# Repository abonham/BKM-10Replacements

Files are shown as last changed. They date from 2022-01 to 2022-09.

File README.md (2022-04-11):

# BKM-10Replacements
BKM-10Replacements are cheap microcontroller based alternative for the Sony BKM-10R control unit typically used with Sony broadcast monitors like the BVM-D20F1a/e/u.

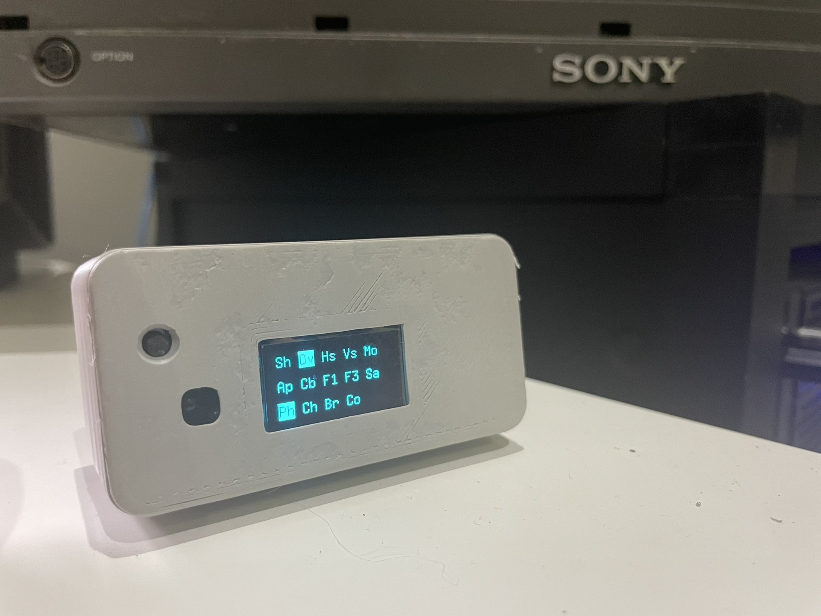
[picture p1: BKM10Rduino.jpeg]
Finished board


The most up-to-date version is BKM10-Rp2040, based on the Raspberry Pico. See the docs in that directory for setup instructions.

## Why?
BVM and PVM CRTs are rather popular with retro gaming enthusiasts, but they are being priced out of reach for the average fan. I managed to rescue a BVM-D20F1A that was destined for e-waste. Of course it was missing the control unit and it was stuck on the SDI input. One spare Arduino Nano, a couple of components, and a lot of swearing later, I had something good enough to use the menus to change inputs and do basic setup. With the help of Martin (@skumlos), this evolved in to a universal IR based replacement.

## What's it do?
Allows the use of almost any IR remote you might have lying around to control any BVM compatible with the BKM-10R. It's configurable through a learning mode, so it's kind of like using a universal remote control, if you remember those from the late 90s. All the buttons on the BKM-10R are replicated, and all status LEDs are displayed on an OLED screen.

There's no problem assembling this on a breadboard, but there are KiCAD schematics, PCB designs and gerber files included if you'd like a more polished finised product.

## Warning
I'm not an electrical engineer. I don't know enough to know when I'm doing something stupid or dangerous. Goes without saying that there is absolutely no warranty; if your precious monitor explodes, I will be very sympathetic and sorry, but that's all. Proceed at your own risk.

If you want to build the PCB version, there are some SMT components, so a least a bit of soldering experience is highly recommended.
## Thanks
I found the control codes on an anonymous [pastebin](https://pastebin.com/aTUWf33J), so must thank this unknown hero.

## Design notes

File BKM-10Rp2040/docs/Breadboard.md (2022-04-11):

# Instructions for building on a breadboard
This is pretty straight forward to build on a breadboard and the only tricky to source part will be the RS485 component.

## BOM
- Raspberry Pico
- [RS485](#rs485) module or IC on breakout
- Hook up wire
- Standard breadboard
- some kind of serial cable

### Optional
#### Display – I2C OLED
- SH1106 or SSD1306

#### IR
- TSOP34xxx IR Receiver
- Remote control w/ 36+ buttons, [NEC IR format](#nec-ir)
- Tact switch (1)

#### Buttons
- Tactile switch/button (5)

## Pinout

|Pin |Dest  |
|---|---|
|GPIO3|IR Out|
|GPIO4 (SDA) | OLED SDA  |
|GPIO5 (SCL) | OLED SCL  |

|Buttons|Pin|
|---|---|
| IR Learn | GPIO2 |
| Power | GPIO15 |
| Menu | GPIO16 |
| Up | GPIO17 |
| Down | GPIO14 |
| Enter | GPIO18 |

### RS485

|RS485|Pin|
|---|---|
|DI|GPIO0 (TX)|
|RO|GPIO1 (RX)|
|DE|GPIO6|
|RE - Full Duplex|GPIO7|
|RE - Half Duplex|GND|

```
GND B   -   -   VCC
1   2   3   4   5
°   °   °   °   ° 
  °   °   °   °
  6   7   8   9    
  -   A   -   -
```
_Looking at front of Male DB9_

### Power
There two ways to power this thing, from USB through the Pico, or directly from the BVM. For initial testing, it is recommended to take power from the Pico, then once it all checks out, switch to take power from the serial cable.

|RS485|Pico|
|---|---|
|VCC|VBUS or VSYS*|
|GND|Any ground|

*If your RS485 solution can operate off 3.3V, then VSYS is the preferred option.

|RS485|DB9|
|---|---|
|VCC|Pin 5|
|GND|Pin 1|

Can also be handy to add a button between RUN and GND for easy reset.

## Firmware
The repo contains two pre-built binaries for the Pico, choose the one that matches you OLED driver, if using a display. If you aren't using the display, then just pick either, it won't matter. 

You can also download pre-built firmware from the latest successful [GitHub action](https://github.com/abonham/BKM-10Replacements/actions)
## Notes
### RS485
There's a few options for RS485: a breakout like the [MAX485](https://core-electronics.com.au/ttl-uart-to-rs485-converter-module.html) or using any bare IC like the [Analog Devices ADM3065E](https://www.analog.com/en/products/adm3065e.html).

If using a breakout board, there don't seem to be any available in full duplex, so it won't be able to receive status updates from the BVM. You can of course just use two; one each for TX and RX.

A bare IC is of course going to require advanced soldering skills and either a SOIC breakout board. With even more advanced skills and it could also be dead bugged.

### NEC IR
Most non-Sony IR remote controls will use the NEC command format, but there are a few other formats out there too. If in doubt, try a couple in learning mode.

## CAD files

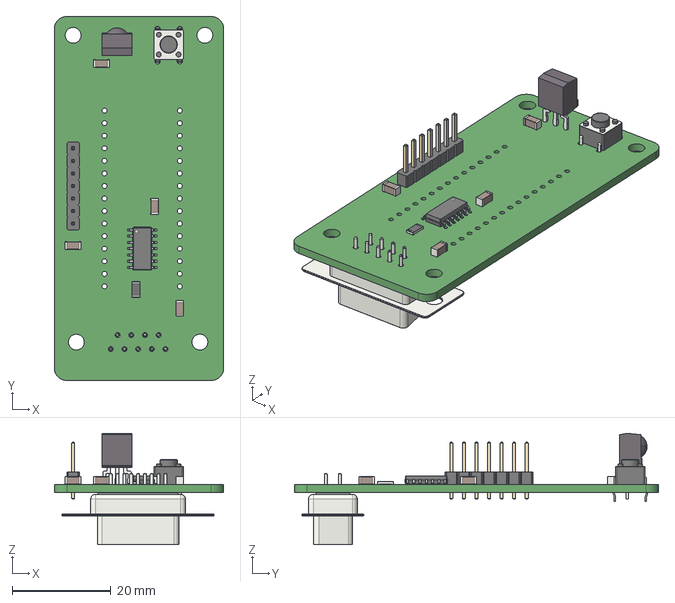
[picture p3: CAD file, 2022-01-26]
BKM-10Rduino/kicad/bkm10iRduino_shield.step
34.3 x 73.7 x 22.5 mm

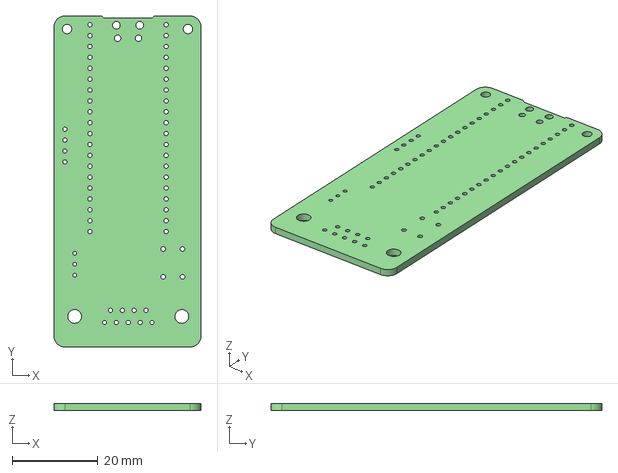
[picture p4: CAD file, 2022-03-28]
BKM-10Rp2040/kicad/BKM-10Rp2040 v2.step
34.3 x 77.2 x 1.60 mm

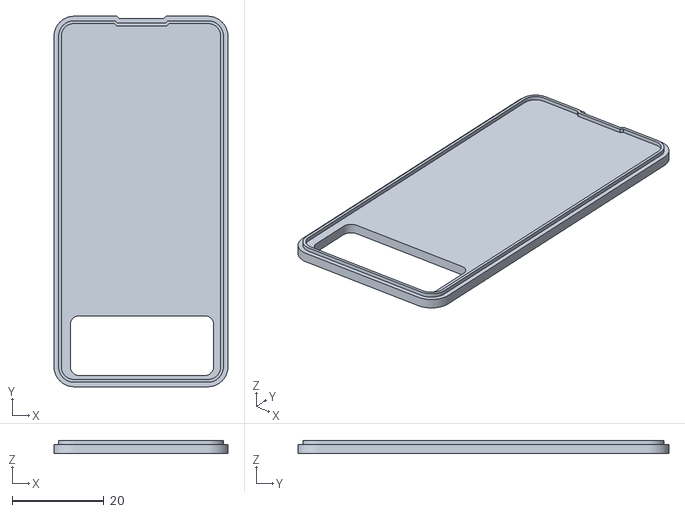
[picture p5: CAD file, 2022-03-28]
BKM-10Rp2040/Lid.stl
38.0 x 80.9 x 2.80

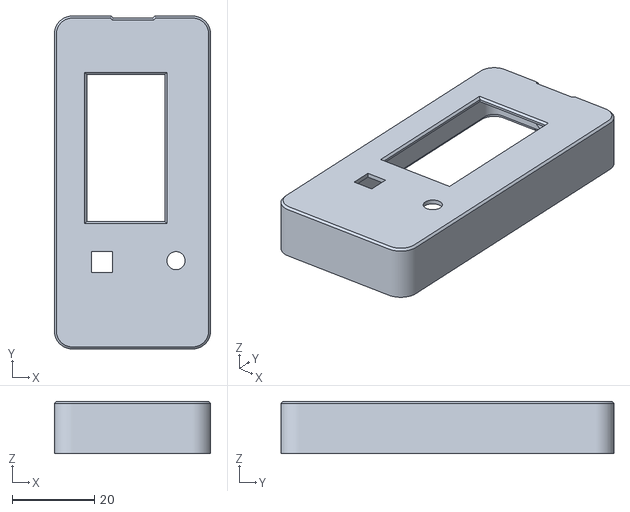
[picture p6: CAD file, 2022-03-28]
BKM-10Rp2040/Case.stl
38.0 x 80.9 x 12.7

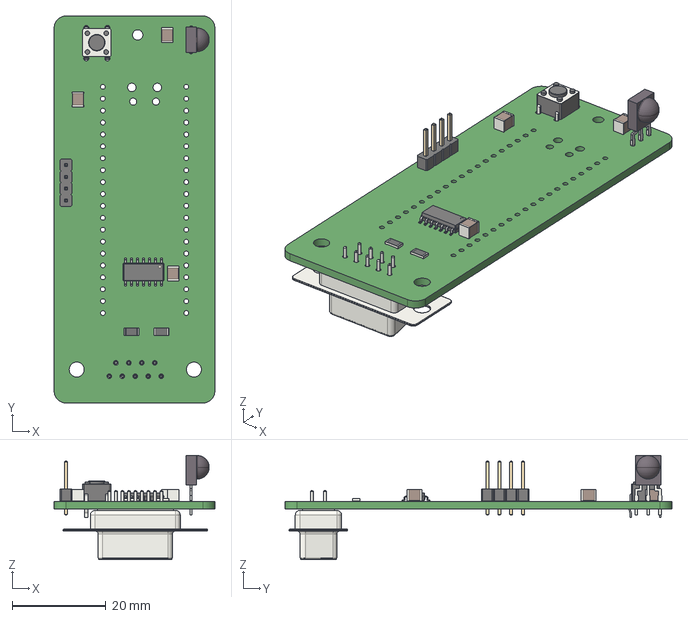
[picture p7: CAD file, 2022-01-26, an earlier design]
BKM-10Rp2040/kicad/BKM-10Rp2040.step
34.3 x 82.5 x 22.2 mm

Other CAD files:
BKM-10Rp2040/bkm2040 v6.f3d

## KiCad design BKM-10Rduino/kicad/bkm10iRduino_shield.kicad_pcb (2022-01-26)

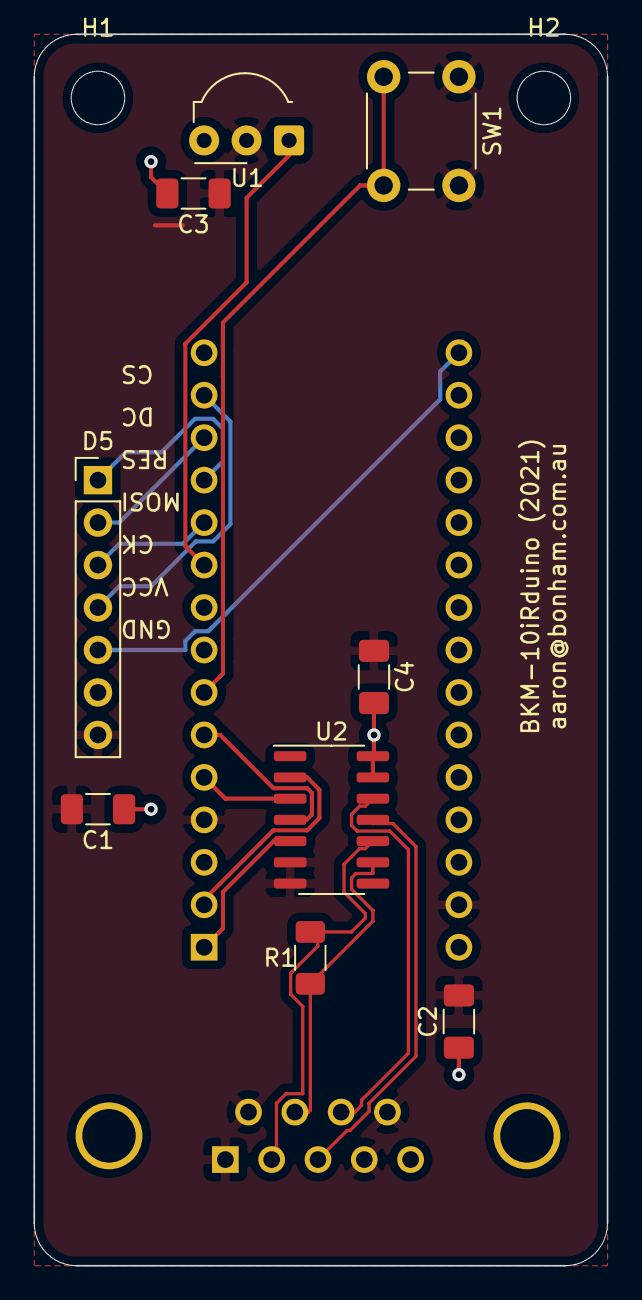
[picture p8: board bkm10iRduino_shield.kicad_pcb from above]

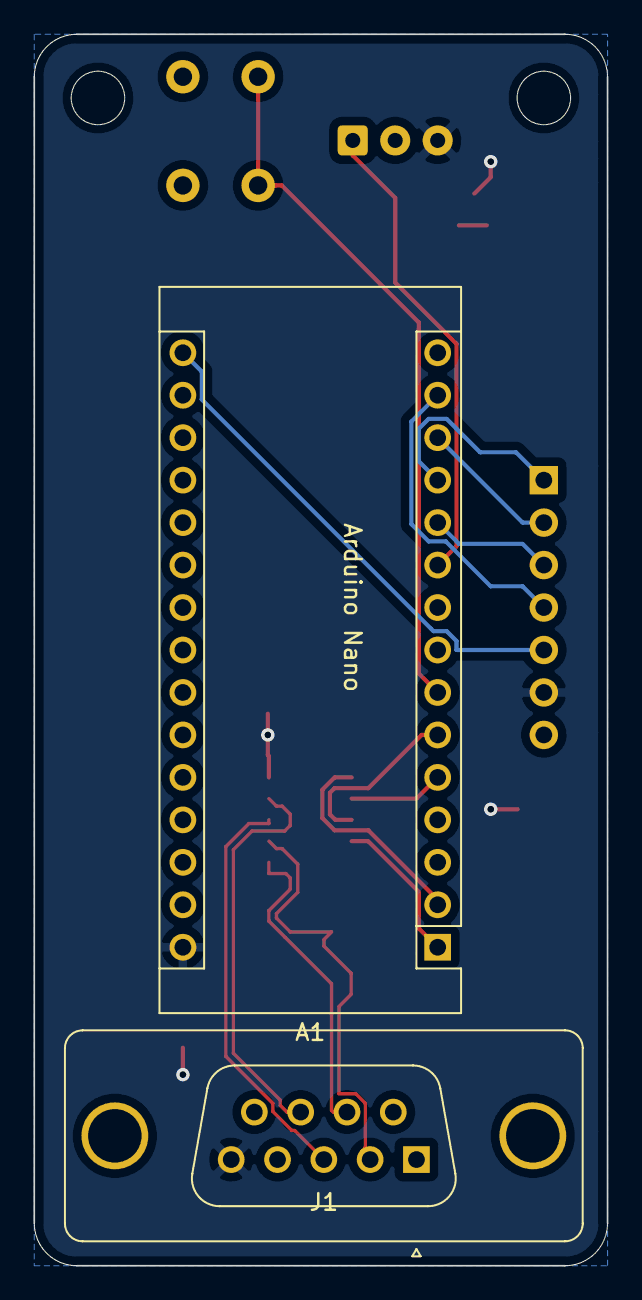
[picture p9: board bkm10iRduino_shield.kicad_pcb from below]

Board: 2 copper layers, 34.3 x 73.7 mm, 13 parts (2 on the bottom side), 17 nets.

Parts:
A1: Arduino_Nano_Every; Arduino_Nano
C1, C2, C3, C4: C_Small; C_1206_3216Metric_Pad1.33x1.80mm_HandSolder
D5: SH1106; PinHeader_1x07_P2.54mm_Vertical
H1, H2: MountingHole; MountingHole_3.2mm_M3
J1: DB9_Male; DSUB-9_Male_Vertical_P2.77x2.84mm_MountingHoles
R1: R; R_1206_3216Metric_Pad1.30x1.75mm_HandSolder
SW1: SW_SPST; SW_PUSH_6mm_H5mm
U1: TSOP343xx; Vishay_MOLD-3Pin
U2: ADM3063EARZ-ND; SOIC-14_3.9x8.7mm_P1.27mm

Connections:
AB+: J1.3, U2.11
AB-: J1.8, U2.12
CS: A1.12, D5.1
DC: A1.13, D5.2
GND: A1.4, A1.29, C1.2, C2.2, C3.1, C4.1, D5.7, J1.1, J1.4, J1.6, J1.9, SW1.1, U1.2, U2.6, U2.7
IR_OUT: A1.10, U1.1
LEARN_BUTTON_IN: A1.7, SW1.2
MOSI: A1.14, D5.4
RES: A1.11, D5.3
RS485_RX: A1.2, U2.2
RS485_RX_ENABLE: A1.5, U2.3
RS485_TX: A1.1, U2.5
RS485_TX_ENABLE: A1.6, U2.4
SCK: A1.16, D5.5
VCC: A1.30, C1.1, C2.1, C3.2, C4.2, D5.6, J1.5, U1.3, U2.13, U2.14
YZ+: J1.7, R1.1, U2.9
YZ-: J1.2, R1.2, U2.10

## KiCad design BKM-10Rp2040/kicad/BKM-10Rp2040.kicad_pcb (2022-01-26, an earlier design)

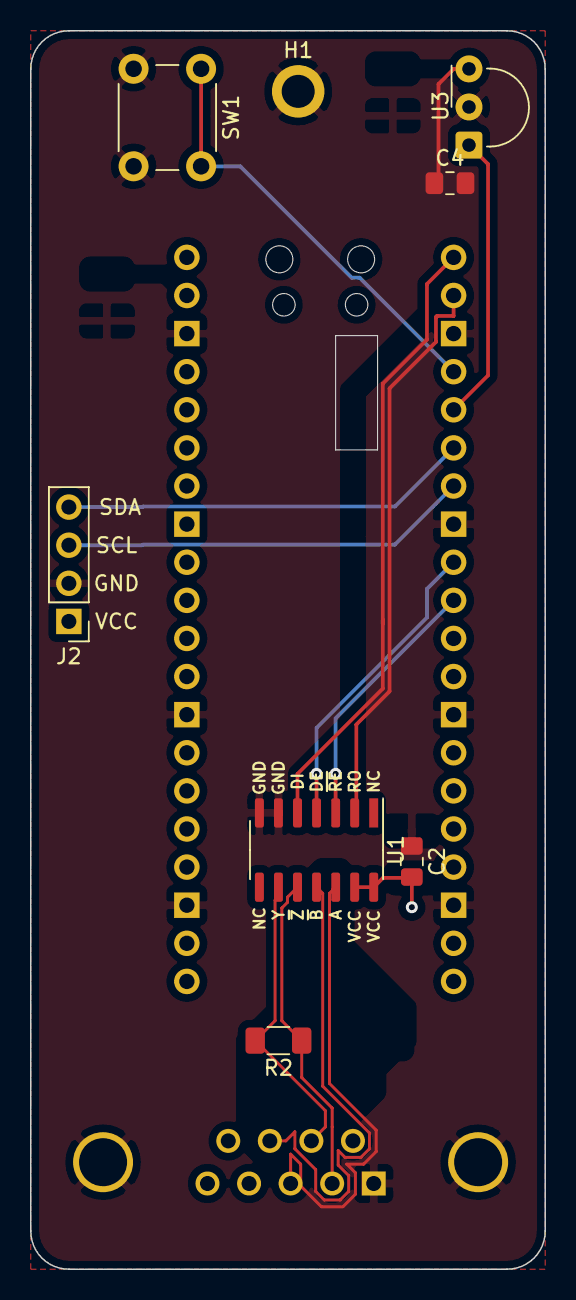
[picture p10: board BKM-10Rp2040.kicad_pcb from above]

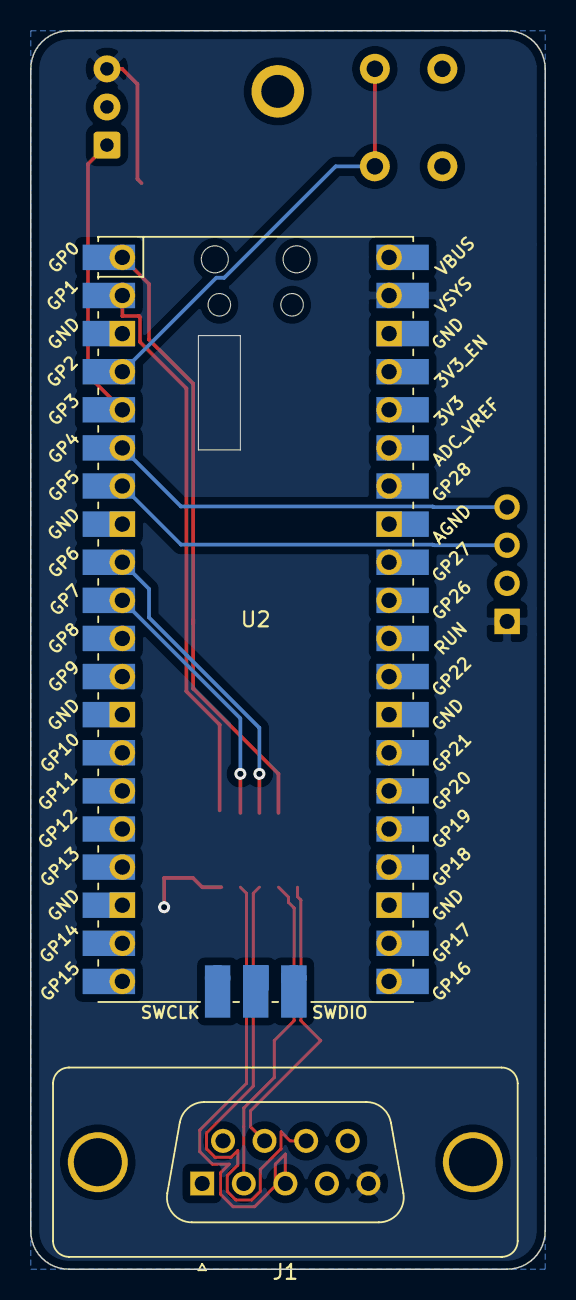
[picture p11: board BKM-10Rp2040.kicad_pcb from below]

Board: 2 copper layers, 34.3 x 82.5 mm, 10 parts (2 on the bottom side), 14 nets.

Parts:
C2, C4: 0.1uF; C_0805_2012Metric_Pad1.18x1.45mm_HandSolder
H1: MountingHole_Pad; MountingHole_2.2mm_M2_ISO7380_Pad
J1: DB9_Female_MountingHoles; DSUB-9_Female_Vertical_P2.77x2.84mm_MountingHoles
J2: Conn_01x04; PinHeader_1x04_P2.54mm_Vertical
R2: 60R; R_1206_3216Metric_Pad1.30x1.75mm_HandSolder
SW1: SW_DPST_x2; SW_PUSH_6mm
U1: ADM3063EARZ-ND; SOIC-14_3.9x8.7mm_P1.27mm
U2: Pico; RPi_Pico_SMD_TH
U3: TSOP335xx; Vishay_MINIMOLD-3Pin

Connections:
+5V: C2.2, C4.1, J1.5, J2.1, U1.13, U1.14, U2.39, U3.3
DE: U1.4, U2.9
GND: C2.1, C4.2, H1.1, J1.0, J1.1, J2.2, SW1.2, U1.6, U1.7, U2.3, U2.8, U2.13, U2.18, U2.23, U2.28, U2.38, U3.2
IR: U2.5, U3.1
LEARN: SW1.1, U2.4
RX: U1.2, U2.2
RXD+: J1.3, U1.12
RXD-: J1.8, U1.11
SCL: J2.3, U2.7
SDA: J2.4, U2.6
TX: U1.5, U2.1
TXD+: J1.7, R2.2, U1.9
TXD-: J1.2, R2.1, U1.10
~RE~: U1.3, U2.10

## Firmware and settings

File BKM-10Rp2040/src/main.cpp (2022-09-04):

// #define SSD1306
#define NO_LED_FEEDBACK_CODE

#include "BKM10Rduino.h"
#include <TinyIRReceiver.h>
#include "IR.h"
#include "store.hpp"
#include "display.h"

extern "C" {
#include "pico.h"
#include "pico/time.h"
#include "pico/bootrom.h"
#include <pico-sdk/rp2_common/hardware_watchdog/include/hardware/watchdog.h>
}
// UART Serial2(0, 1, NC, NC);
// #define CLEAR_STORED_KEYS

#define MENU_BUTTON_PIN 16
#define ENTER_BUTTON_PIN 18
#define UP_BUTTON_PIN 17
#define POWER_BUTTON_PIN 15
#define DOWN_BUTTON_PIN 14
#define RIGHT_BUTTON_PIN 13

#define REBOOT_BUTTON_PIN 22
#define SOFT_REBOOT_PIN 20

#define WAIT_FOR_BOOT false
#define IR_DEBOUNCE 16
#define BUTTON_DEBOUNCE 200

CircularBuffer<void *, 4> commandBuffer;
CircularBuffer<ControlCode, 4> encoderBuffer;

volatile bool learning = false;
volatile bool isHoldingLearnButton = false;
volatile bool handledButtonPress = true;

uint8_t learnIndex = 0;
int rebootPressCount = 0;
bool rebootPressed = false;

bool displaySleep = false;

enum bank selectedBank = none;
volatile uint8_t selectedEncoder = 0x00;

LEDStatus ledStatus = LEDStatus();
struct RemoteKey *learningInput = (RemoteKey *)malloc(sizeof(RemoteKey));
struct RemoteKey *lastLearnedInput = (RemoteKey *)malloc(sizeof(RemoteKey));
struct ControlCode *lastRemoteInput = (ControlCode *)malloc(sizeof(ControlCode));
struct Timers *timers = (Timers *)malloc(sizeof(Timers));

volatile int lastDebounce = 0;

// #define SH1106
#define SCREEN_WIDTH 128 // OLED display width, in pixels
#define SCREEN_HEIGHT 64 // OLED display height, in pixels
TwoWire i2c(4, 5);
#ifdef SSD1306
Adafruit_SSD1306 display(SCREEN_WIDTH, SCREEN_HEIGHT, &i2c, -1);
#else
#include "Adafruit_SH110X.h"
Adafruit_SH1106G display(SCREEN_WIDTH, SCREEN_HEIGHT, &i2c, -1);
#endif
StoreClass store = StoreClass();
const char *keysFileName = MBED_LITTLEFS_FILE_PREFIX "/keys.json";

#define BAUD_RATE 38400

char requestLEDS[] = {0x44, 0x33, 0x31};

String debugMessage = String("");

void setText(const char *msg)
{
  display.clearDisplay();
  display.setTextColor(WHITE);
  display.setCursor(10, 0);
  display.println(msg);
  display.display();
}

void setText(String msg) {
  setText(msg.c_str());
}

void setupPins()
{
  pinMode(LEARN_ENABLE_PIN, INPUT_PULLUP);
  pinMode(LED_BUILTIN, OUTPUT);
  pinMode(IR_INPUT_PIN, INPUT);

  pinMode(TX_ENABLE_PIN, OUTPUT);
  pinMode(RX_ENABLE_LOW_PIN, OUTPUT);
  digitalWrite(TX_ENABLE_PIN, HIGH);
  digitalWrite(RX_ENABLE_LOW_PIN, LOW);

  pinMode(POWER_BUTTON_PIN, INPUT_PULLUP);
  pinMode(MENU_BUTTON_PIN, INPUT_PULLUP);
  pinMode(ENTER_BUTTON_PIN, INPUT_PULLUP);
  pinMode(UP_BUTTON_PIN, INPUT_PULLUP);
  pinMode(DOWN_BUTTON_PIN, INPUT_PULLUP);

  pinMode(REBOOT_BUTTON_PIN, INPUT_PULLUP);
  pinMode(SOFT_REBOOT_PIN, INPUT_PULLUP);
}

void setup()
{
  setupPins();
  if (!gpio_get(LEARN_ENABLE_PIN))
  {
    reset_usb_boot(0, 0);
  }

  Serial.begin(BAUD_RATE);
  Serial1.begin(BAUD_RATE);
#ifdef DIAGNOSTIC
  while (gpio_get(LEARN_ENABLE_PIN)) {
    // connect serial then press button to continue boot
  }
#endif

#ifdef SSD1306
  display.begin(SSD1306_SWITCHCAPVCC, 0x3c);
#else
  display.begin();
#endif
  display.clearDisplay();
  display.display();

  store.initFS();
#ifdef CLEAR_STORED_KEYS
  remove(keysFileName);
#endif
  setText("BKM-10Rp2040");
  delay(500);
  int err = store.loadKeys(keysFileName);
  delay(100);
  if (err != Ok)
  {
    setText((char *)store.errorMsg(err));
    learning = true;
  }
  else
  {
    updateLEDS(&display, &ledStatus, false);
  }
  delay(500);

  *learningInput = {0, 0};
  *lastLearnedInput = {0, 0};
  *lastRemoteInput = {0, 0};

  attachInterrupt(digitalPinToInterrupt(3), handleIR, CHANGE);

  unsigned long mark = millis();
  timers->lastPoll = mark;
  timers->learnHold = mark;
  timers->lastInput = mark;
  timers->lastRemoteInput = mark;
  Serial1.write("ICC");
  Serial1.write("IMT");
  Serial1.write(requestLEDS);
}

void loop()
{
  processControlMessages(timers, &ledStatus);
  if (ledStatus.needsUpdate)
  {
    logLEDs(&ledStatus);
  }
  processCommandBuffer(&commandBuffer);
  processEncoderQueue(&encoderBuffer, selectedBank);
  updateState();
}

// MARK:- IR receiver interupt handlers
// void handleReceivedTinyIRData(unsigned short address, unsigned char data, bool repeat)
void handleReceivedTinyIRData(uint16_t aAddress, uint8_t aCommand, bool isRepeat)
{
  timers->lastInput = millis();
  if (!learning)
  {
    handleRemoteCommand(aAddress, aCommand, isRepeat);
  }
  else
  {
    learnRemoteCommand(aAddress, aCommand, isRepeat);
  }
}

int commandIndex(RemoteKey key) {
  int x = sizeof(commands) / sizeof(Command);
  for (int i = 0; i < x; i++)
  {
    RemoteKey k = store.getKey(i);
    if (equals(k, key))
    {
      return i;
    }
  }
  return -1;
}

int commandIndex(ControlCode code) {
  int x = sizeof(commands) / sizeof(Command);
  for (int i = 0; i < x; i++)
  {
    Command command = commands[i];
    if (command.cmd.group == code.group && command.cmd.code == code.code)
    {
      return i;
    }
  }
  return -1;
}

void handleRemoteCommand(uint16_t aAddress, uint8_t aCommand, bool isRepeat)
{
  // debugMessage = debugMessage + "\nNew IR =>" + String(aAddress, HEX) + " " + String(aCommand, HEX);

  RemoteKey input = {aAddress, aCommand, 99};

  unsigned long mark = millis();

  int i = commandIndex(input);
  if (i == -1) {
    return;
  }
  ControlCode *toSend = (ControlCode *)&commands[i].cmd;
  if (toSend->group == ENCODER_GROUP)
  {
    digitalWrite(LED_BUILTIN, HIGH);
    handleRotaryEncoderCommand(toSend, isRepeat);
  }
  else if ((!isRepeat || commands[i].repeats) && mark - timers->lastRemoteInput > IR_DEBOUNCE)
  { // remote will set isRepeat when holding down buttons that aren't supposed to "pulse"
    digitalWrite(LED_BUILTIN, HIGH);
    commandBuffer.push(toSend);
    lastRemoteInput = toSend;
    timers->lastRemoteInput = mark;
  }
  return;
}

void handleRotaryEncoderCommand(ControlCode *toSend, bool repeating)
{
  if (toSend->code == 0 && !repeating)
  {
    // Change selected rotary encoder
    int next = selectedEncoder + 1;
    selectedEncoder = next <= 3 ? next : 0;
    ledStatus.selectedEncoder = selectedEncoder;
  }
  else
  {
    ControlCode newCode = {};
    newCode.group = selectedEncoder;
    newCode.code = toSend->code;
    encoderBuffer.push(newCode);
  }
}

// MARK:- Learn remote control
void updateIsLearning()
{
  unsigned long mark = millis();
  bool learnTimePassed = mark - timers->learnHold > LEARN_TIMEOUT;
  bool quickPress = mark - timers->learnHold > BUTTON_DEBOUNCE;
  bool wasHoldingUserButton = mark - timers->learnHold < BUTTON_DEBOUNCE * 3;

  int learnButtonState = digitalRead(LEARN_ENABLE_PIN);
  bool pressed = learnButtonState == LOW;

  if (pressed && displaySleep) {
    timers->lastInput = mark;
    delay(BUTTON_DEBOUNCE * 2);
    return;
  }

  if (pressed && quickPress && !isHoldingLearnButton)
  {
    isHoldingLearnButton = true;
    timers->learnHold = mark;
    timers->lastInput = mark;
    handledButtonPress = false;
    return;
  }

  if (!learning && isHoldingLearnButton && !learnTimePassed && pressed) {
    return;
  }

  if (!pressed
      && !handledButtonPress
      && quickPress
      && wasHoldingUserButton)
  //didn't hold longer than learn or reboot and no action taken yet
  {
    isHoldingLearnButton = false;
    handledButtonPress = true;
    timers->lastInput = mark;
    if (learning)
    {
        cancelLearning();
        return;
    }

    //user action
    // button released after debounce, so treat as user action
    ControlCode *toSend = (ControlCode *)&commands[31].cmd;
    digitalWrite(LED_BUILTIN, HIGH);
    commandBuffer.push(toSend);
    drawBigText(&display, String(degauss), SCREEN_WIDTH, SCREEN_HEIGHT);
    delay(1000);
    return;
  }

  else if (!pressed)
  //clear holding button state if button has been released
  {
    isHoldingLearnButton = false;
    return;
  }

  if (learning)
  {
    if (pressed && mark - timers->lastInput > REBOOT_TIMEOUT && !handledButtonPress) {
      reset_usb_boot(0, 0);
    }
  }
  else if (pressed && !handledButtonPress && learnTimePassed)
  {
    learning = true;
    handledButtonPress = true;
    learnIndex = 0;
    processLearnQueue();
  }
}

void cancelLearning()
{
#ifdef SERIAL_LOGGING
  Serial.println("cancel learning");
#endif
  learning = false;
  learningInput->address = 0;
  learningInput->code = 0;
  lastLearnedInput->address = 0;
  lastLearnedInput->code = 0;
  learnIndex = 0;
}

void reboot() {
  reset_usb_boot(1<<PICO_DEFAULT_LED_PIN,0);
}

void processLearnQueue()
{
  if (learnIndex >= COMMANDS_SIZE)
  {
    if (store.saveStoredKeys(keysFileName) == 0)
    {
      setText("save ok");
      delay(1000);
    }
    cancelLearning();
    return;
  }

  if (learningInput->address == 0)
  {
    return;
  }

  RemoteKey newKey = {learningInput->address, learningInput->code, learnIndex};

  #ifdef DIAGNOSTIC
  RemoteKey old = store.getKey(learnIndex);
  Serial.print(learnIndex);

  Serial.print(" - old: (");
  Serial.print(old.address);
  Serial.print(",");
  Serial.print(old.code);
  Serial.print("), ");


  Serial.print("new: (");
  Serial.print(newKey.address);
  Serial.print(",");
  Serial.print(newKey.code);
  Serial.print("), ");

  Serial.print("id: ");
  Serial.println(newKey.id);
  #endif

  int err = store.putKey(learnIndex, newKey, false);
  if (err != StorageError::Ok)
  {
    Serial.println("failed to save new key");
  }

  lastLearnedInput->address = newKey.address;
  lastLearnedInput->code = newKey.code;
  learningInput->address = 0;
  learningInput->code = 0;
  learnIndex++;
}

void learnRemoteCommand(uint16_t aAddress, uint8_t aCommand, bool isRepeat)
{
  // Easy ignore for holding ir button too long
  // Don't double process keys that don't send isRepeat, like vol +/-
  if (isRepeat || (aAddress == lastLearnedInput->address && aCommand == lastLearnedInput->code))
  {
    return;
  }
  // Since we are coming from an interupt, don't process if main thread hasn't finished processing last command
  if (learningInput->address)
  {
    return;
  }

  RemoteKey incoming = {aAddress, aCommand, 0};

  if (!equals(incoming, *lastLearnedInput))
  {
    learningInput->address = aAddress;
    learningInput->code = aCommand;
  }
}

void handleButtonState(byte state) {
  digitalWrite(LED_BUILTIN, HIGH);
  if (bitRead(state,0)) {
      commandBuffer.push((ControlCode *)&commands[0].cmd);
  }
  else if (bitRead(state,1)) {
      commandBuffer.push((ControlCode *)&commands[1].cmd);
  }
  else if (bitRead(state,2)) {
      commandBuffer.push((ControlCode *)&commands[2].cmd);
  }
  else if (bitRead(state,3)) {
      commandBuffer.push((ControlCode *)&commands[3].cmd);
  }
  else if (bitRead(state,4)) {
      commandBuffer.push((ControlCode *)&commands[4].cmd);
  }
}

void checkPhysicalButtons() {
  if (digitalRead(REBOOT_BUTTON_PIN) == LOW) {
    reset_usb_boot(1<<PICO_DEFAULT_LED_PIN,0);
  }

  if (digitalRead(SOFT_REBOOT_PIN) == LOW) {
    // Use pico watch dog to soft reboot
    watchdog_enable(1, 1);
    while(1);
    return;
  }

  ButtonState btnState = {0};

  if (!(millis() - lastDebounce > IR_DEBOUNCE)) {
    return;
  }

  if (digitalRead(POWER_BUTTON_PIN) == LOW) {
    bitSet(btnState.state, 0);
    Serial.println("power on from button");
  }
  if (digitalRead(MENU_BUTTON_PIN) == LOW) {
    bitSet(btnState.state, 1);
    Serial.println("menu from button");
  }
  if (digitalRead(ENTER_BUTTON_PIN) == LOW) {
    bitSet(btnState.state, 2);
    Serial.println("enter from button");
  }
  if (digitalRead(UP_BUTTON_PIN) == LOW) {
    bitSet(btnState.state, 3);
    Serial.println("up from button");
  }
  if (digitalRead(DOWN_BUTTON_PIN) == LOW) {
    bitSet(btnState.state, 4);
    Serial.println("down from button");
  }

  lastDebounce = millis();

  if (btnState.state) {
    handleButtonState(btnState.state);
  }
}

void updateState()
{
  unsigned long mark = millis();
  if (mark - timers->lastPoll > POLL_RATE)
  {
    digitalWrite(LED_BUILTIN, LOW);
    checkPhysicalButtons();
    powerSave(timers, &displaySleep);
    updateIsLearning();

    // Do serial console output here as it's too slow to do during IR interupt
    if (debugMessage != "")
    {
      Serial.println(debugMessage);
      debugMessage = "";
    }

    int i = commandIndex(*lastRemoteInput);
    if (learning && (learnIndex < COMMANDS_SIZE))
    {
      updateDisplay(&display, learnIndex, SCREEN_WIDTH, SCREEN_HEIGHT);
    }
    else if (i != -1 && mark - timers->lastRemoteInput < 200) {
      drawBigText(&display, String(names[i]), SCREEN_WIDTH, SCREEN_HEIGHT);
    }
    else
    {
      updateLEDS(&display, &ledStatus, displaySleep);
    }
    timers->lastPoll = mark;
  }
}

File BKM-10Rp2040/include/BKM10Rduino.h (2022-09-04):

#ifndef __BKM10R_H
#define __BKM10R_H

#define COMMANDS_SIZE 35
#define IR_INPUT_PIN 3
#define TX_ENABLE_PIN 6
#define RX_ENABLE_LOW_PIN 7
#define LEARN_ENABLE_PIN 2
#define LEARN_TIMEOUT 3000
#define REBOOT_TIMEOUT 6000
#define SLEEP_TIMER 180000
#define CIRCULAR_BUFFER_INT_SAFE
#define SERIAL_LOGGING
#define __ASSERT_USE_STDERR
#define POLL_RATE 33
#define TICK_RATE 100

#include <Arduino.h>
#include "CircularBuffer.h"
#include <Wire.h>
#include <Adafruit_GFX.h>

enum bank
{
  ISW,
  ILE,
  IEN,
  IMT,
  ICC,
  DATA,
  none
};

/*
 * Holds any timestamps required for time based events
 */
struct Timers
{
  unsigned long lastPoll;
  unsigned long learnHold;
  unsigned long lastInput;
  unsigned long lastRemoteInput;
};

const byte keydown = 0x44;
const char ISWBank[] = "ISW";
const char IENBank[] = "IEN";

struct RemoteKey
{
  uint16_t address;
  uint8_t code;
  uint8_t id;
};

extern RemoteKey remoteKey;

/*
 * Two byte BKM-10R control code
 *
 * Codes are sent over RS485 as `keydown, group, code`
 */
struct ControlCode
{
  byte group;
  byte code;
};

extern ControlCode controlCode;

struct RotaryEncoder
{
  byte encoderId;
};

struct ButtonState
{
  byte state;
};

struct Command
{
  struct ControlCode cmd;
  bool repeats;
  uint8_t id;
};

extern Command command;

const char power[] = "Power";
const char menu[] = "Menu";
const char enter[] = "Enter";
const char up[] = "Up";
const char down[] = "Down";
const char zero[] = "0";
const char one[] = "1";
const char two[] = "2";
const char three[] = "3";
const char four[] = "4";
const char five[] = "5";
const char six[] = "6";
const char seven[] = "7";
const char eight[] = "8";
const char nine[] = "9";
const char del[] = "Del";
const char ent[] = "Ent";
const char shiftSel[] = "Shift";
const char overscan[] = "Overscan/16:9";
const char hsync[] = "HSync/Sync";
const char vsync[] = "VSync/Blue";
const char mono[] = "Mono/R";
const char apt[] = "Apt/G";
const char comb[] = "Comb/B";
const char f1[] = "F1/F2";
const char f3[] = "F3/F4";
const char safe_area[] = "Safe Area/Address";
const char phase[] = "Phase manual";
const char chroma[] = "Chroma manual";
const char bright[] = "Brigtness manual";
const char contrast[] = "Contrast manual";
const char degauss[] = "Degauss";
const char encoderSwitch[] = "Next rotary";
const char encoderUp[] = "Rotary up";
const char encoderDown[] = "Rotary down";

const char *const names[] = {
    power,
    menu,
    enter,
    up,
    down,
    zero,
    one,
    two,
    three,
    four,
    five,
    six,
    seven,
    eight,
    nine,
    del,
    ent,
    shiftSel,
    overscan,
    hsync,
    vsync,
    mono,
    apt,
    comb,
    f1,
    f3,
    safe_area,
    phase,
    chroma,
    bright,
    contrast,
    degauss,
    encoderSwitch,
    encoderUp,
    encoderDown,
};

#define BKM_POWER \
  {               \
    0x01, 0x10    \
  }
#define BKM_MENU \
  {              \
    0x02, 0x10   \
  }
#define BKM_ENTER \
  {               \
    0x02, 0x20    \
  }
#define BKM_UP \
  {            \
    0x02, 0x40 \
  }
#define BKM_DOWN \
  {              \
    0x02, 0x80   \
  }
#define BKM_ZERO \
  {              \
    0x00, 0x01   \
  }
#define BKM_ONE \
  {             \
    0x00, 0x02  \
  }
#define BKM_TWO \
  {             \
    0x00, 0x04  \
  }
#define BKM_THREE \
  {               \
    0x00, 0x08    \
  }
#define BKM_FOUR \
  {              \
    0x00, 0x10   \
  }
#define BKM_FIVE \
  {              \
    0x00, 0x20   \
  }
#define BKM_SIX \
  {             \
    0x00, 0x40  \
  }
#define BKM_SEVEN \
  {               \
    0x00, 0x80    \
  }
#define BKM_EIGHT \
  {               \
    0x01, 0x01    \
  }
#define BKM_NINE \
  {              \
    0x01, 0x02   \
  }
#define BKM_DEL \
  {             \
    0x01, 0x04  \
  }
#define BKM_ENT \
  {             \
    0x01, 0x08  \
  }
#define BKM_SHIFT \
  {               \
    0x03, 0x01    \
  }
#define BKM_OVERSCAN \
  {                  \
    0x03, 0x02       \
  } // OVERSCAN / 16:9
#define BKM_H_SYNC \
  {                \
    0x03, 0x04     \
  } // HORIZ SYNC VIEW / SYNC
#define BKM_V_SYNC \
  {                \
    0x03, 0x08     \
  } // VERT SYNC VIEW / BLUE ONLY
#define BKM_MONO \
  {              \
    0x03, 0x10   \
  } // MONO / R
#define BKM_APT \
  {             \
    0x04, 0x01  \
  } // APT / G
#define BKM_COMB \
  {              \
    0x04, 0x02   \
  } // COMB / B
#define BKM_F1 \
  {            \
    0x04, 0x04 \
  } // F1 / F3
#define BKM_F3 \
  {            \
    0x04, 0x08 \
  } // F2 / F4
#define BKM_SAFE_AREA \
  {                   \
    0x04, 0x10        \
  } // SAFE AREA / ADDRESS
#define BKM_PHASE \
  {               \
    0x02, 0x08    \
  } // PHASE MANUAL
#define BKM_CHROMA \
  {                \
    0x02, 0x04     \
  } // CHROMA MANUAL
#define BKM_BRIGHT \
  {                \
    0x02, 0x02     \
  } // BRIGHT MANUAL
#define BKM_CONTRAST \
  {                  \
    0x02, 0x01       \
  } // CONTRAST MANUAL
#define BKM_DEGAUSS \
  {                 \
    0x01, 0x20      \
  } // DEGAUSS

// LED Group 2
#define LED_CONTRAST 0x01
#define LED_BRIGHT 0x02
#define LED_CHROMA 0x04
#define LED_PHASE 0x08

// LED Group 3
#define LED_SHIFT 0x01
#define LED_OVERSCAN 0x02
#define LED_H_SYNC 0x04
#define LED_V_SYNC 0x08
#define LED_MONO 0x10

// LED Group 4
#define LED_APT 0x01
#define LED_COMB 0x02
#define LED_F1 0x04
#define LED_F3 0x08
#define LED_SAFE_AREA 0x10

#define ENCODER_GROUP 0x05 // arbitrary new group for rotary encoders

#define IEN_SWITCH      \
  {                     \
    ENCODER_GROUP, 0x00 \
  }
#define IEN_UP          \
  {                     \
    ENCODER_GROUP, 0x01 \
  }
#define IEN_DOWN        \
  {                     \
    ENCODER_GROUP, 0x02 \
  }

const struct Command commands[] = {
    {BKM_POWER, false, 0},
    {BKM_MENU, false, 1},
    {BKM_ENTER, false, 2},
    {BKM_UP, true, 3},
    {BKM_DOWN, true, 4},
    {BKM_ZERO, false, 5},
    {BKM_ONE, false, 6},
    {BKM_TWO, false, 7},
    {BKM_THREE, false, 8},
    {BKM_FOUR, false, 9},
    {BKM_FIVE, false, 10},
    {BKM_SIX, false, 11},
    {BKM_SEVEN, false, 12},
    {BKM_EIGHT, false, 13},
    {BKM_NINE, false, 14},
    {BKM_DEL, true, 15},
    {BKM_ENT, false, 16},
    {BKM_SHIFT, false, 17},
    {BKM_OVERSCAN, false, 18},
    {BKM_H_SYNC, false, 19},
    {BKM_V_SYNC, false, 20},
    {BKM_MONO, false, 21},
    {BKM_APT, false, 22},
    {BKM_COMB, false, 23},
    {BKM_F1, false, 24},
    {BKM_F3, false, 25},
    {BKM_SAFE_AREA, false, 26},
    {BKM_PHASE, false, 27},
    {BKM_CHROMA, false, 28},
    {BKM_BRIGHT, false, 29},
    {BKM_CONTRAST, false, 30},
    {BKM_DEGAUSS, false, 31},
    {IEN_SWITCH, false, 32},
    {IEN_UP, true, 33},
    {IEN_DOWN, true, 34},
};

struct LEDStatus
{
  enum bank currentBank = none;
  int group2LEDMask = 0;
  int group3LEDMask = 0;
  int group4LEDMask = 0;
  bool needsUpdate = false;
  int selectedEncoder = 0;
};
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

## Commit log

2022-01-26 initial migration
    [BKM-10Rp2040 v2-B_Cu.gbr, BKM-10Rp2040 v2-B_Mask.gbr, BKM-10Rp2040 v2-B_Paste.gbr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]
2022-03-06 fix display on SH1106
    [BKM-10Rp2040 v2.kicad_pcb, BKM-10Rp2040 v2.step]
2022-03-06 cad files for case
    [Case.stl, Lid.stl, bkm2040 v6.f3d]
2022-03-13 add new case models
    [BKM-10Rp2040 v2.kicad_pcb, Case.stl, Lid.stl]
2022-03-31 start adding button support back in
2022-04-11 pin lib version
2022-05-01 fix remote learning and add new defult IR remote
    [BKM10Rduino.h, main.cpp, store.cpp]
